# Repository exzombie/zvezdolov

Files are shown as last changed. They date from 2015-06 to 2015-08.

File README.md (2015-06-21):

# Zvezdolov

Zvezdolov ("Starcatcher") is a device for measuring stellar
brightness. I consists of a LED light mounted on a fishpole and
control knobs for adjusting the color and brightnes of the light. The
fishpole serves to keep the light as far away as practical from the
user, thus making it more similar to a point source. The user orients
the fishpole so that the light is visually near a star and adjusts the
color and brightness to match the star. A display on the control board
shows the apparent magnitude of the star.

This repository contains work in progress on a color version of such a
device. The previous prototype used a white LED and would not work
well on reddish stars. Currently, the circuit design is complete, but
untested. There is no software yet because the main LED driver chip is
not breadboard-friendly and a PCB has to be made first.

# Authors

Jure Varlec <jure.varlec@ad-vega.si>

Based on a white LED version by Andrej Lajovic
<andrej.lajovic@ad-vega.si>.

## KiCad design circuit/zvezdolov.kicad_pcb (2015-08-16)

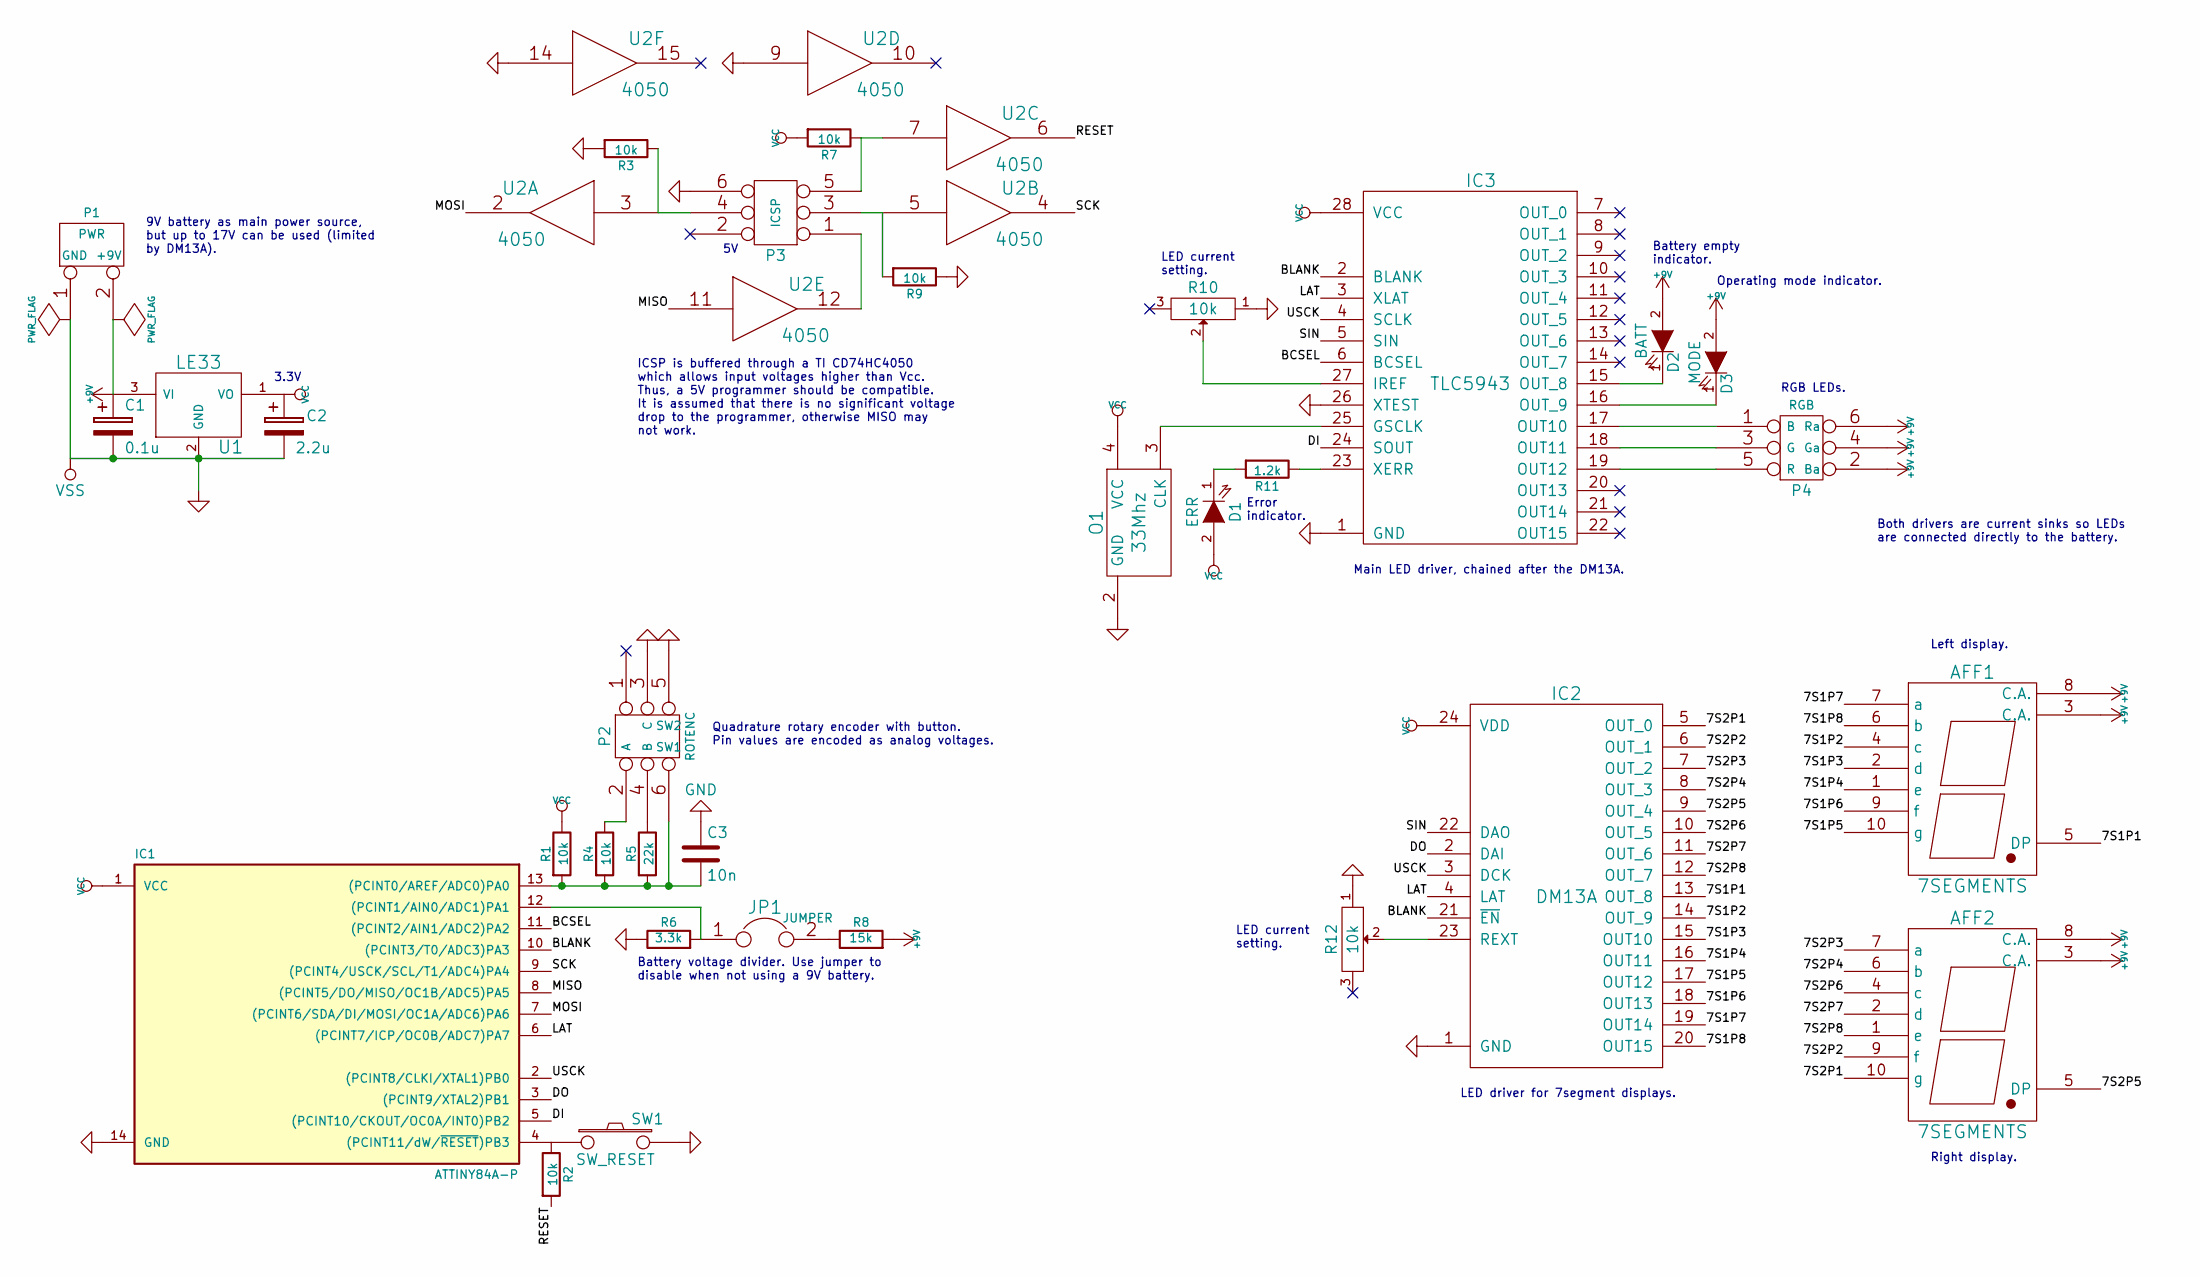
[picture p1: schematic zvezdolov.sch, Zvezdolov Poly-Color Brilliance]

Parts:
AFF1, AFF2: 7SEGMENTS; 7SegmentLED_LTS6760_LTS6780
C1: 0.1u; C_Rect_L7_W3.5_P5
C2: 2.2u; C_Radial_D5_L11_P2.5
C3: 10n; C_Rect_L7_W3.5_P5
D1: ERR; LED-5MM
D2: BATT; LED-5MM
D3: MODE; LED-5MM
IC1: ATTINY84A-P; DIP-14__300
IC2: DM13A; DIP-24__300
IC3: TLC5943; TSSOP-28_4.4x9.7mm_Pitch0.65mm
JP1: JUMPER; Pin_Header_Straight_1x02
O1: 33Mhz; Oscillator_SMD_7x5
P1: PWR; Pin_Header_Straight_1x02
P2: ROTENC; Pin_Header_Straight_2x03
P3: ICSP; Pin_Header_Straight_2x03
P4: RGB; Pin_Header_Straight_2x03
R1, R2, R3, R4, R7, R9: 10k; R3
R5: 22k; R3
R6: 3.3k; R3
R8: 15k; R3
R10, R12: 10k; TRIM
R11: 1.2k; R3
SW1: SW_RESET; SW_PUSH_SMALL
U1: LE33; TO-92_Molded_Wide_Reverse
U2: 4050; DIP-16__300

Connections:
+9V: AFF1.3 (C.A.), AFF1.8 (C.A.), AFF2.3 (C.A.), AFF2.8 (C.A.), C1.1, D2.2 (A), D3.2 (A), P1.2 (PM), P4.2, P4.4, P4.6, R8.2, U1.3 (VI)
/7S1P1: AFF1.5 (DP), IC2.13 (OUT_8)
/7S1P2: AFF1.4 (c), IC2.14 (OUT_9)
/7S1P3: AFF1.2 (d), IC2.15 (OUT10)
/7S1P4: AFF1.1 (e), IC2.16 (OUT11)
/7S1P5: AFF1.10 (g), IC2.17 (OUT12)
/7S1P6: AFF1.9 (f), IC2.18 (OUT13)
/7S1P7: AFF1.7 (a), IC2.19 (OUT14)
/7S1P8: AFF1.6 (b), IC2.20 (OUT15)
/7S2P1: AFF2.10 (g), IC2.5 (OUT_0)
/7S2P2: AFF2.9 (f), IC2.6 (OUT_1)
/7S2P3: AFF2.7 (a), IC2.7 (OUT_2)
/7S2P4: AFF2.6 (b), IC2.8 (OUT_3)
/7S2P5: AFF2.5 (DP), IC2.9 (OUT_4)
/7S2P6: AFF2.4 (c), IC2.10 (OUT_5)
/7S2P7: AFF2.2 (d), IC2.11 (OUT_6)
/7S2P8: AFF2.1 (e), IC2.12 (OUT_7)
/BCSEL: IC1.11 ((PCINT2/AIN1/ADC2)PA2), IC3.6 (BCSEL)
/BLANK: IC1.10 ((PCINT3/T0/ADC3)PA3), IC2.21 (~EN), IC3.2 (BLANK)
/DI: IC1.5 ((PCINT10/CKOUT/OC0A/INT0)PB2), IC3.24 (SOUT)
/DO: IC1.3 ((PCINT9/XTAL2)PB1), IC2.2 (DAI)
/LAT: IC1.6 ((PCINT7/ICP/OC0B/ADC7)PA7), IC2.4 (LAT), IC3.3 (XLAT)
/MISO: IC1.8 ((PCINT5/DO/MISO/OC1B/ADC5)PA5), U2.11
/MOSI: IC1.7 ((PCINT6/SDA/DI/MOSI/OC1A/ADC6)PA6), U2.2
/RESET: R2.2, U2.6
/SCK: IC1.9 ((PCINT4/USCK/SCL/T1/ADC4)PA4), U2.4
/SIN: IC2.22 (DAO), IC3.5 (SIN)
/USCK: IC1.2 ((PCINT8/CLKI/XTAL1)PB0), IC2.3 (DCK), IC3.4 (SCLK)
unnamed: C3.2, IC1.13 ((PCINT0/AREF/ADC0)PA0), P2.6, R1.2, R4.2, R5.2
unnamed: D1.1 (K), R11.2
unnamed: D2.1 (K), IC3.15 (OUT_8)
unnamed: D3.1 (K), IC3.16 (OUT_9)
unnamed: IC1.4 ((PCINT11/dW/~RESET~)PB3), R2.1, SW1.1
unnamed: IC1.12 ((PCINT1/AIN0/ADC1)PA1), JP1.1, R6.2
unnamed: IC2.23 (REXT), R12.2
unnamed: IC3.17 (OUT10), P4.1
unnamed: IC3.18 (OUT11), P4.3
unnamed: IC3.19 (OUT12), P4.5
unnamed: IC3.23 (XERR), R11.1
unnamed: IC3.25 (GSCLK), O1.3 (CLK)
unnamed: IC3.27 (IREF), R10.2
unnamed: JP1.2, R8.1
unnamed: P2.2, R4.1
unnamed: P2.4, R5.1
unnamed: P3.1, U2.12
unnamed: P3.3, R9.2, U2.5
unnamed: P3.4, R3.1, U2.3
unnamed: P3.5, R7.1, U2.7
VCC: C2.1, D1.2 (A), IC1.1 (VCC), IC2.24 (VDD), IC3.28 (VCC), O1.4 (VCC), R1.1, R7.2, U1.1 (VO), U2.1 (VCC)
VSS: C1.2, C2.2, C3.1, IC1.14 (GND), IC2.1 (GND), IC3.1 (GND), IC3.26 (XTEST), O1.2 (GND), P1.1, P2.3, P2.5, P3.6, R3.2, R6.1, R9.1, R10.1, R12.1, SW1.2, U1.2 (GND), U2.8 (VSS), U2.9, U2.14

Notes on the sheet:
3.3V
Battery voltage divider. Use jumper to disable when not using a 9V battery.
9V battery as main power source, but up to 17V can be used (limited by DM13A).
Quadrature rotary encoder with button. Pin values are encoded as analog voltages.
LED driver for 7segment displays.
Battery empty indicator.
Main LED driver, chained after the DM13A.
Both drivers are current sinks so LEDs are connected directly to the battery.
Error indicator.
LED current setting.
Operating mode indicator.
RGB LEDs.
Left display.
Right display.
ICSP is buffered through a TI CD74HC4050 which allows input voltages higher than Vcc. Thus, a 5V programmer should be compatible. It is assumed that there is no significant voltage drop to the programmer, otherwise MISO may not work.

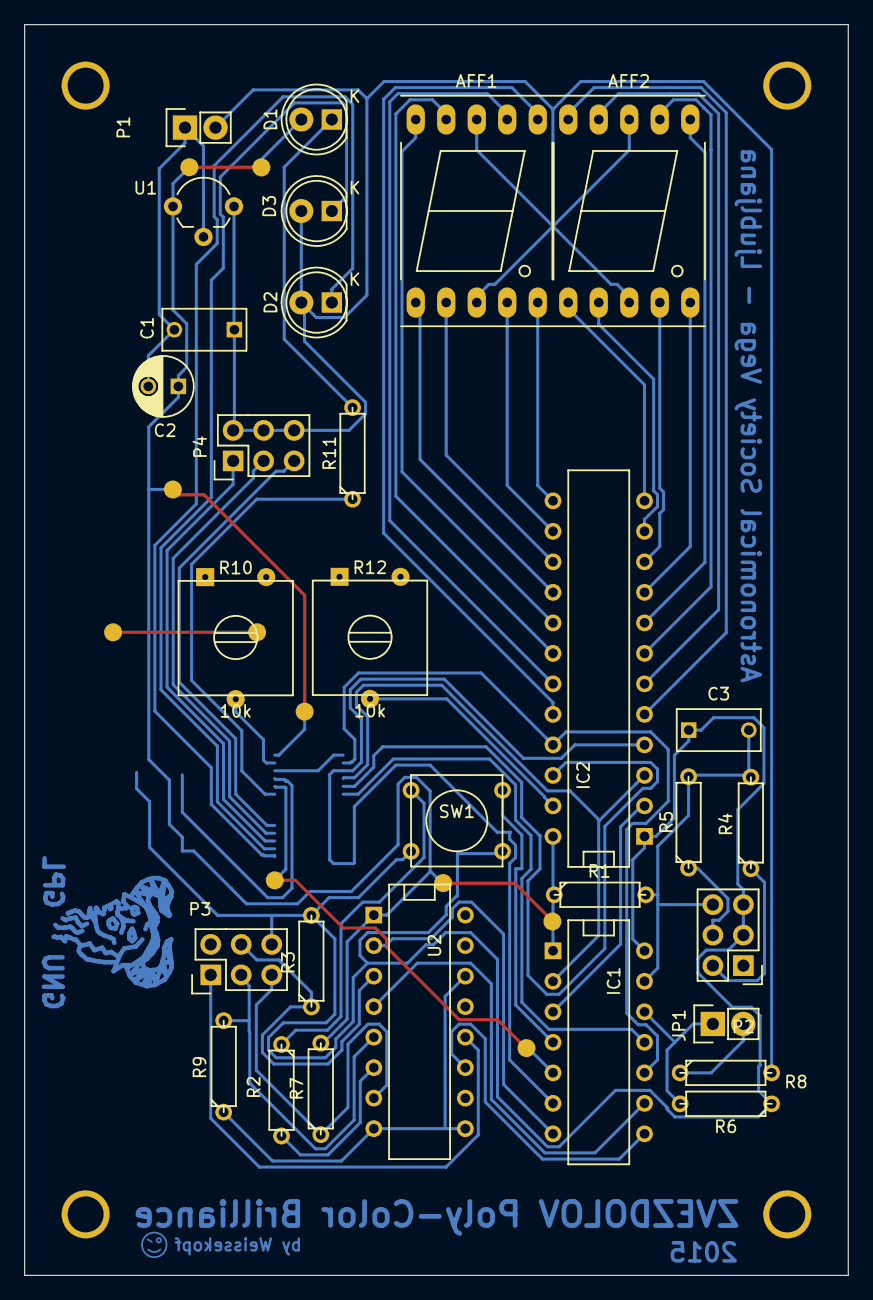
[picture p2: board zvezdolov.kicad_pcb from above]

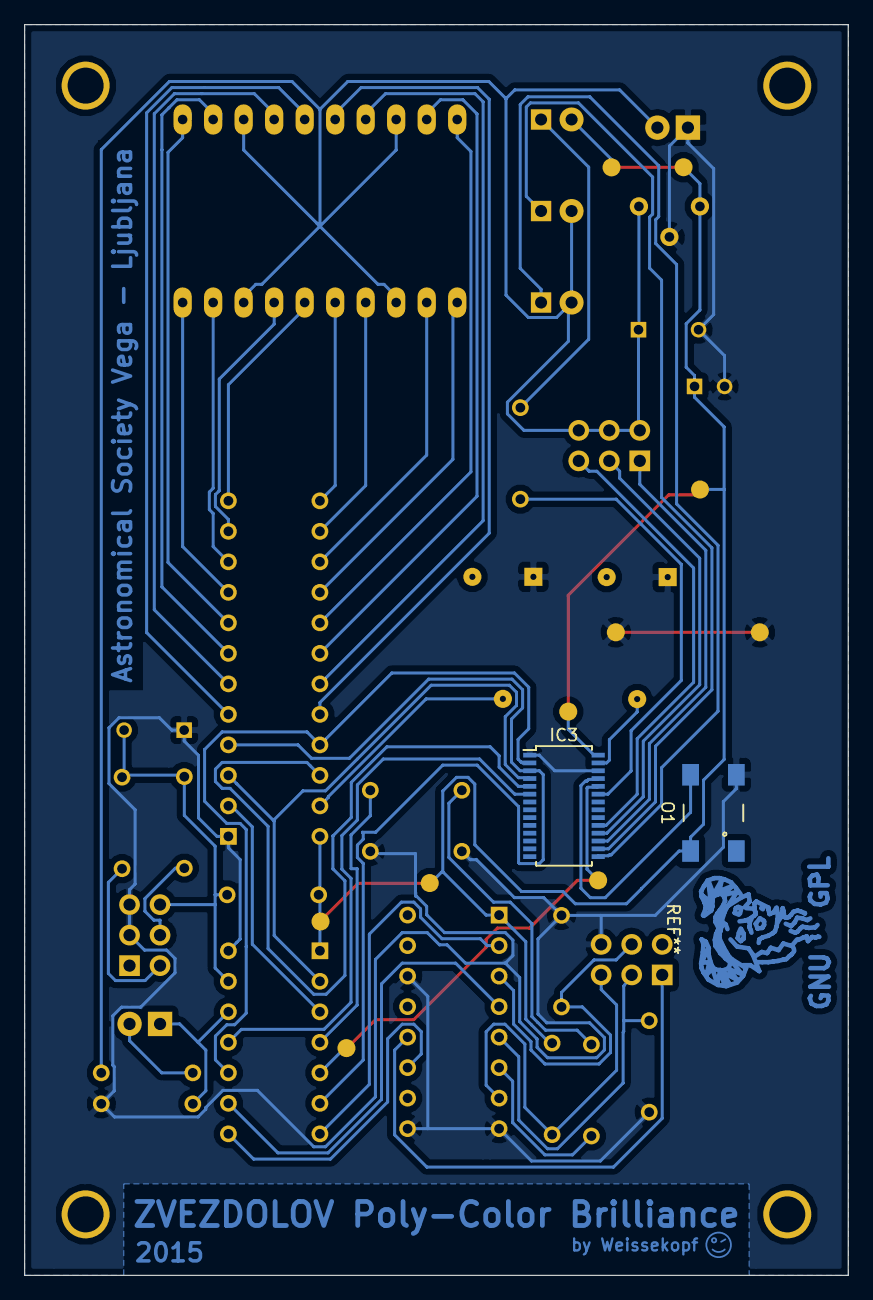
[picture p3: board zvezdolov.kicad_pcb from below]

Board: 2 copper layers, 68.6 x 104.1 mm, 36 parts (2 on the bottom side), 50 nets.

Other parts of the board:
MOUNT1, MOUNT2, MOUNT3, MOUNT4: MountingHole_3mm

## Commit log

2015-06-21 Initial import.
    [zvezdolov.kicad_pcb, zvezdolov.sch]
2015-06-21 Add a debounce capacitor to the encoder.
    [zvezdolov.kicad_pcb, zvezdolov.sch]
2015-06-21 Move some components slightly.
    [zvezdolov.sch]
2015-06-21 PCB text tweaks.
    [zvezdolov.kicad_pcb]
2015-06-26 Make the PCB considerably smaller.
    [zvezdolov.kicad_pcb]
2015-06-27 Fix texts, add logos and bump PCB revision.
    [zvezdolov.kicad_pcb, zvezdolov.sch]
2015-07-31 Move a wire pad from under IC3 where it was in the way.
    [zvezdolov.kicad_pcb]
2015-08-16 Fix the broken ICSP setup.
    [zvezdolov.kicad_pcb, zvezdolov.sch]
